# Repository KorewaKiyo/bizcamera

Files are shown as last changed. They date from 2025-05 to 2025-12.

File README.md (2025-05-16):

# BizCamera 
## A credit/business card sized camera

### Why?
I thought it was a cool and silly enough idea to be unique, and I couldn't find anyone else doing it. So I took it on myself to make it happen.

### How?
Initially I wanted to go with something STM32, as the camera module wants 1.8V, and there were some good STM32 MCUs with 1.8v, but it seemed like none of them were fast enough or had enough RAM to grab frames from the sensor. 
So I'm using the RP2350 which with PIO should have enough IO speed to just steal a frame off the data bus.

The chip itself doesn't have enough ram to store an image above 320x240 so I've added some RAM, a flash chip for code, and an SD card slot for storing images.

### What's the output like?
Yet to be seen :>

### What does the board look like?

top
bottom
rendered with [kicad-render](https://github.com/linalinn/kicad-render)

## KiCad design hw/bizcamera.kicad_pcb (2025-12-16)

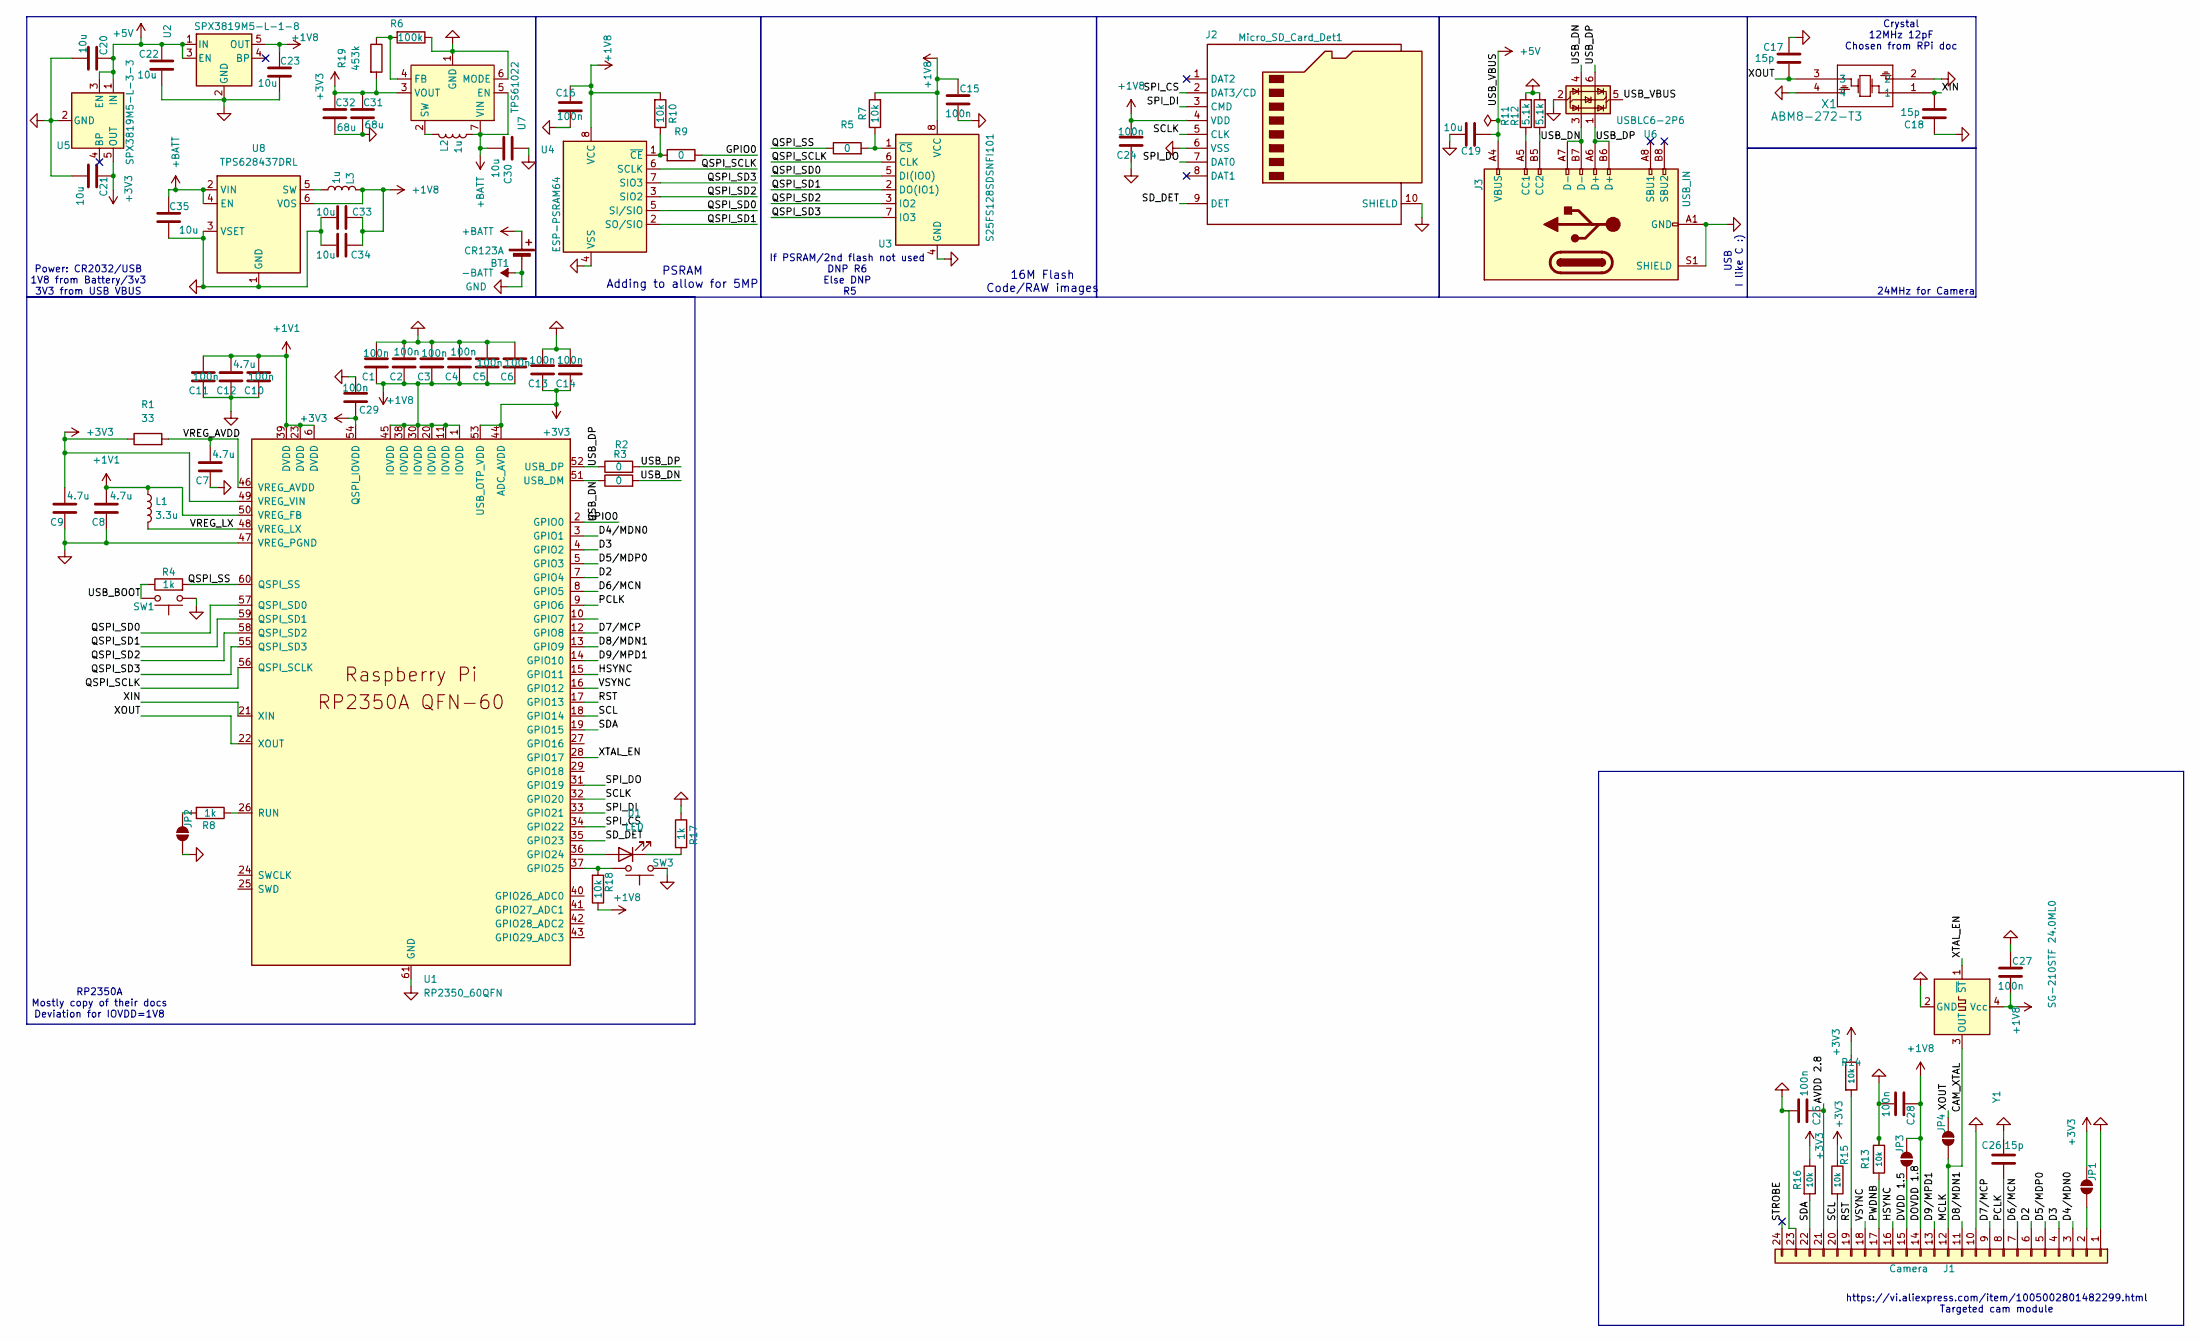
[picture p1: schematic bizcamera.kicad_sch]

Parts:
BT1: CR123A; BatteryHolder_Bulgin_BX0123_1xCR123
C1, C2, C3, C4, C5, C6, C10, C11, C13, C14, C15, C16, C24, C25, C27, C28, C29: 100n; C_0402_1005Metric; LCSC C1525
C7, C8, C9, C12: 4.7u; C_0402_1005Metric; LCSC C76995
C17, C18, C26: 15p; C_0402_1005Metric; LCSC C1548
C19, C20, C21, C22, C23, C30, C33, C34, C35: 10u; C_0603_1608Metric; LCSC C1691
C31, C32: 68u; C_0603_1608Metric; LCSC C7220
D1: LED; LED_1206_3216Metric_ReverseMount_Hole1.8x2.4mm; LCSC C329183
J1: Camera; Hirose_FH12-24S-0.5SH_1x24-1MP_P0.50mm_Horizontal; LCSC C202112
J2: Micro_SD_Card_Det1; microSD_HC_Hirose_DM3D-SF; LCSC C719027
J3: USB_IN; USB_C_Receptacle_HCTL_HC-TYPE-C-16P-01A; LCSC C2894897
JP1: CAM_AF; SolderJumper-2_P1.3mm_Open_RoundedPad1.0x1.5mm
JP2: USB_BOOT; SolderJumper-2_P1.3mm_Open_RoundedPad1.0x1.5mm
JP3: DVDD_1V8; SolderJumper-2_P1.3mm_Open_RoundedPad1.0x1.5mm
JP4: XTAL_JMP; SolderJumper-2_P1.3mm_Open_RoundedPad1.0x1.5mm
L1: 3.3u; L_pol_2016
L2, L3: 1u; TFM201610ALMA; LCSC C404808
R1: 33; R_0402_1005Metric; LCSC C25105
R2, R3, R5, R9: 0; R_0402_1005Metric; LCSC C17168
R4, R8, R17: 1k; R_0402_1005Metric; LCSC C11702
R6: 100k; R_0402_1005Metric_Pad0.72x0.64mm_HandSolder; LCSC C25741
R7, R10, R13, R14, R15, R16, R18: 10k; R_0603_1608Metric; LCSC C15401
R11, R12: 5.1k; R_0603_1608Metric; LCSC C23186
R19: 453k; R_0402_1005Metric_Pad0.72x0.64mm_HandSolder; LCSC C103049
SW1: USB_BOOT; SW_Push_1P1T_NO_CK_KMR2; LCSC C72443
SW3: Shutter; SW_Push_1P1T_NO_6x6mm_H9.5mm; LCSC C22397173
U1: RP2350_60QFN; RP2350-QFN-60-1EP_7x7_P0.4mm_EP3.4x3.4mm_ThermalVias; LCSC C42411118
U2: SPX3819M5-L-1-8; SOT-23-5; LCSC C18212663
U3: S25FS128SDSNFI101; WSON-8-1EP_6x5mm_P1.27mm_EP3.4x4.3mm; LCSC C2954241
U4: ESP-PSRAM64; SOIC-8_3.9x4.9mm_P1.27mm
U5: SPX3819M5-L-3-3; SOT-23-5; LCSC C5370980
U6: USBLC6-2P6; SOT-666; LCSC C2682291
U7: TPS61022; Texas_RWU0007A_VQFN-7_2x2mm_P0.5mm; LCSC C915088
U8: TPS628437DRL; SOT-563; LCSC C25838674
X1: ABM8-272-T3; ABM8-272-T3_ABR; LCSC C20625731
Y1: SG-210STF 24.0ML0; Oscillator_SMD_SeikoEpson_SG210-4Pin_2.5x2.0mm

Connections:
+1V1: C8.1, C10.1, C11.1, C12.1, L1.1, U1.6 (DVDD), U1.23 (DVDD), U1.39 (DVDD), U1.50 (VREG_FB)
+1V8: C1.2, C2.2, C3.2, C4.2, C5.2, C6.2, C15.2, C16.2, C23.1, C24.1, C27.1, C28.2, C33.1, C34.1, J1.14, J2.4 (VDD), JP3.1 (A), L3.2, R7.2, R10.2, R18.1, U1.1 (IOVDD), U1.11 (IOVDD), U1.20 (IOVDD), U1.30 (IOVDD), U1.38 (IOVDD), U1.45 (IOVDD), U2.5 (OUT), U3.8 (VCC), U4.8 (VCC), U8.6 (VOS), Y1.4 (Vcc)
+3V3: C9.1, C13.2, C14.2, C21.1, C29.2, C31.1, C32.1, JP1.1 (A), R1.1, R14.1, R15.1, R16.1, R19.2, U1.44 (ADC_AVDD), U1.49 (VREG_VIN), U1.53 (USB_OTP_VDD), U1.54 (QSPI_IOVDD), U5.5 (OUT), U7.3 (VOUT)
+5V: C19.2, C20.1, C22.1, J3.A4 (VBUS), J3.A9 (VBUS), J3.B4 (VBUS), J3.B9 (VBUS), U2.1 (IN), U2.3 (EN), U5.1 (IN), U5.3 (EN), U6.5 (VBUS)
+BATT: BT1.1 (+), C30.2, C35.1, L2.1, U7.5 (EN), U7.7 (VIN), U8.2 (VIN), U8.4 (EN)
-BATT: BT1.2 (-), C1.1, C2.1, C3.1, C4.1, C5.1, C6.1, C7.2, C8.2, C9.2, C10.2, C11.2, C12.2, C13.1, C14.1, C15.1, C16.1, C17.2, C18.2, C19.1, C20.2, C21.2, C22.2, C23.2, C24.2, C25.1, C26.1, C27.2, C28.1, C29.1, C30.1, C31.2, C32.2, C33.2, C34.2, C35.2, J1.1, J1.10, J1.23, J2.6 (VSS), J2.10 (SHIELD), J3.A1 (GND), J3.A12 (GND), J3.B1 (GND), J3.B12 (GND), J3.S1 (SHIELD), JP2.2 (B), R6.1, R11.2, R12.2, R13.1, R17.1, SW1.1, SW3.1, U1.47 (VREG_PGND), U1.61 (GND), U2.2 (GND), U3.4 (GND), U4.4 (VSS), U5.2 (GND), U6.2 (GND), U7.1 (GND), U7.6 (MODE), U8.1 (GND), U8.3 (VSET), X1.2, X1.4, Y1.2 (GND)
/AVDD 2.8: C25.2, J1.21
/CAM_XTAL: J1.12, JP4.2 (B), Y1.3 (OUT)
/D2: J1.6, U1.7 (GPIO4)
/D3: J1.4, U1.4 (GPIO2)
/D4/MDN0: J1.3, U1.3 (GPIO1)
/D5/MDP0: J1.5, U1.5 (GPIO3)
/D6/MCN: J1.7, U1.8 (GPIO5)
/D7/MCP: J1.9, U1.12 (GPIO8)
/D8/MDN1: J1.11, U1.13 (GPIO9)
/D9/MPD1: J1.13, U1.14 (GPIO10)
/DVDD 1.5: J1.15, JP3.2 (B)
/GPIO0: R9.1, U1.2 (GPIO0)
/HSYNC: J1.16, U1.15 (GPIO11)
/PCLK: C26.2, J1.8, U1.9 (GPIO6)
/PWDNB: J1.17, R13.2
/QSPI_SCLK: U1.56 (QSPI_SCLK), U3.6 (CLK), U4.6 (SCLK)
/QSPI_SD0: U1.57 (QSPI_SD0), U3.5 (DI(IO0)), U4.5 (SI/SIO)
/QSPI_SD1: U1.59 (QSPI_SD1), U3.2 (DO(IO1)), U4.2 (SO/SIO)
/QSPI_SD2: U1.58 (QSPI_SD2), U3.3 (IO2), U4.3 (SIO2)
/QSPI_SD3: U1.55 (QSPI_SD3), U3.7 (IO3), U4.7 (SIO3)
/QSPI_SS: R4.2, R5.1, U1.60 (QSPI_SS)
/RST: J1.19, R14.2, U1.17 (GPIO13)
/SCL: J1.20, R15.2, U1.18 (GPIO14)
/SCLK: J2.5 (CLK), U1.32 (GPIO20)
/SDA: J1.22, R16.2, U1.19 (GPIO15)
/SD_DET: J2.9 (DET), U1.35 (GPIO23)
/SPI_CS: J2.2 (DAT3/CD), U1.34 (GPIO22)
/SPI_DI: J2.3 (CMD), U1.33 (GPIO21)
/SPI_DO: J2.7 (DAT0), U1.31 (GPIO19)
/STROBE: J1.24
/USB_BOOT: R4.1, SW1.2
/USB_DN: J3.A7 (D-), J3.B7 (D-), R3.1, R3.2, U1.51 (USB_DM), U6.3 (I/O2), U6.4 (I/O2)
/USB_DP: J3.A6 (D+), J3.B6 (D+), R2.1, R2.2, U1.52 (USB_DP), U6.1 (I/O1), U6.6 (I/O1)
/VREG_AVDD: C7.1, R1.2, U1.46 (VREG_AVDD)
/VREG_LX: L1.2, U1.48 (VREG_LX)
/VSYNC: J1.18, U1.16 (GPIO12)
/XIN: C18.1, U1.21 (XIN), X1.1
/XOUT: C17.1, JP4.1 (A), U1.22 (XOUT), X1.3
/XTAL_EN: U1.28 (GPIO17), Y1.1 (~ST)
unnamed: D1.2 (A), U1.36 (GPIO24)
unnamed: D1.1 (K), R17.2
unnamed: J1.2, JP1.2 (B)
unnamed: J3.A5 (CC1), R11.1
unnamed: J3.B5 (CC2), R12.1
unnamed: JP2.1 (A), R8.2
unnamed: R18.2, SW3.2, U1.37 (GPIO25)
unnamed: R8.1, U1.26 (RUN)
unnamed: R5.2, R7.1, U3.1 (~CS)
unnamed: R9.2, R10.1, U4.1 (~CE)
unnamed: R6.2, R19.1, U7.4 (FB)
unnamed: L2.2, U7.2 (SW)
unnamed: L3.1, U8.5 (SW)

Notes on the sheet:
16M Flash Code/RAW images
USB I like C :)
Crystal 12MHz 12pF Chosen from RPi doc
If PSRAM/2nd flash not used DNP R6 Else DNP R5
Power: CR2032/USB 1V8 from Battery/3v3 3V3 from USB VBUS
24MHz for Camera
PSRAM Adding to allow for 5MP
RP2350A Mostly copy of their docs Deviation for IOVDD=1V8
https://vi.aliexpress.com/item/1005002801482299.html Targeted cam module

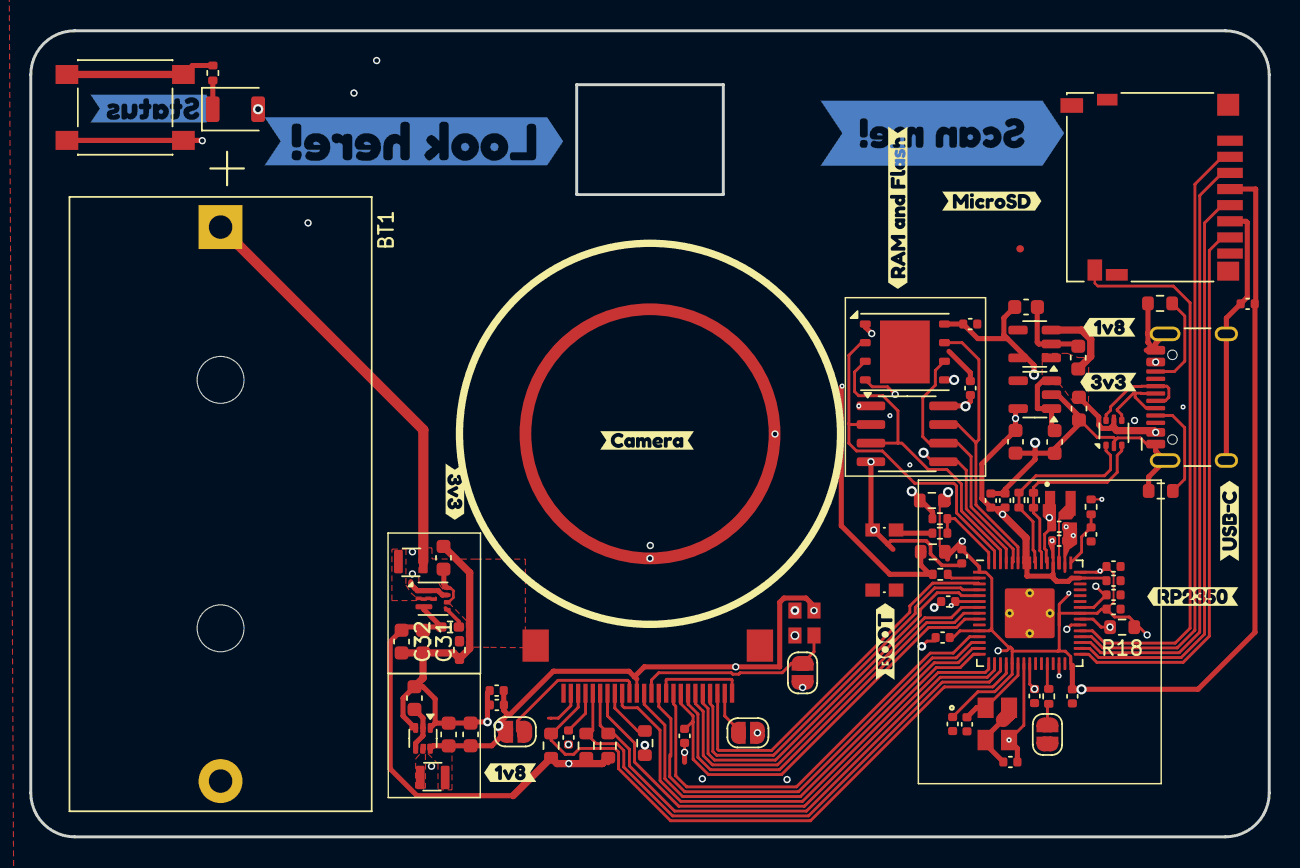
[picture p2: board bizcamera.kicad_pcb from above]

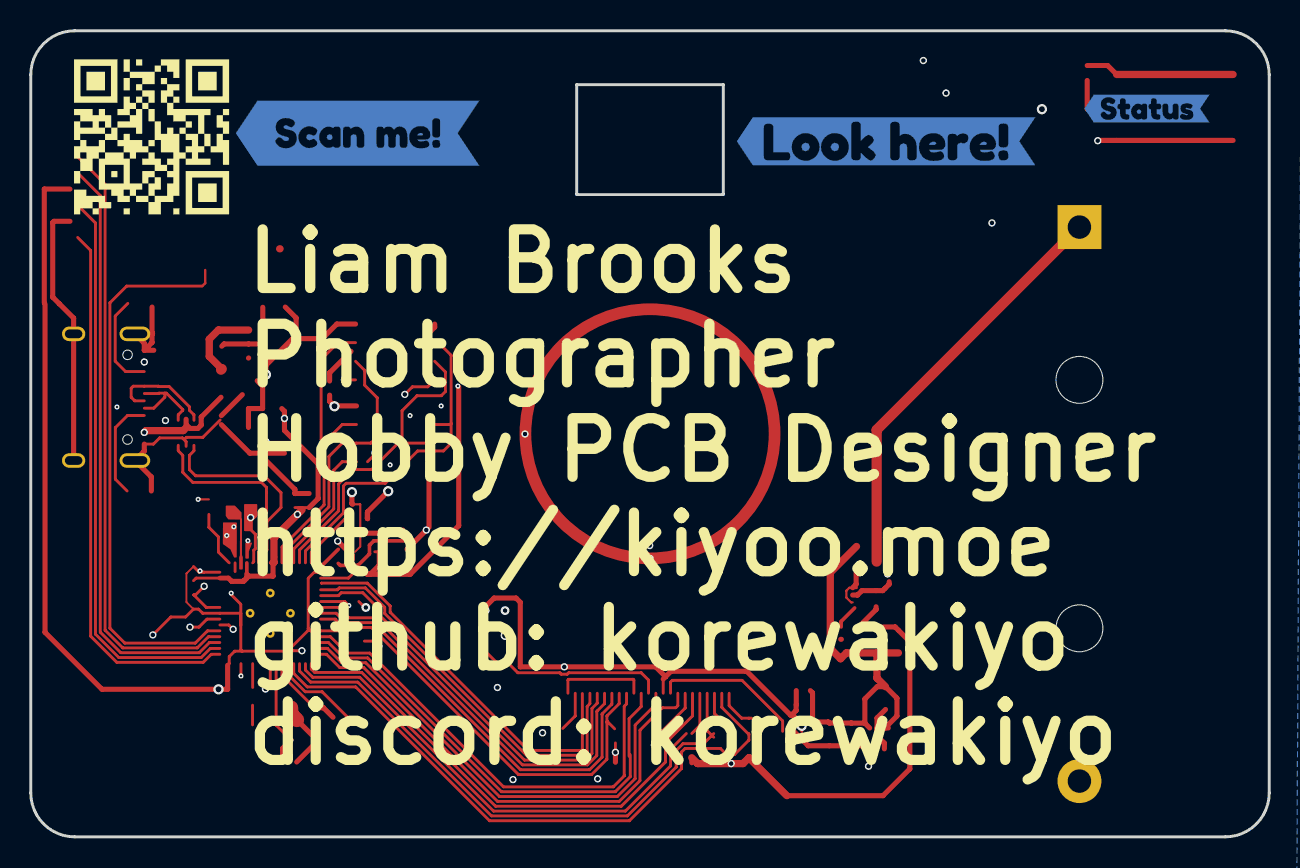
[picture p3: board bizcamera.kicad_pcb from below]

Board: 4 copper layers, 84.5 x 55.0 mm, 92 parts (3 on the bottom side), 57 nets.

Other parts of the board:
kibuzzard-6825B58C: G***; kibuzzard-6825B58C
kibuzzard-68265B48: G***; kibuzzard-68265B48
kibuzzard-68265CCE: G***; kibuzzard-68265CCE
kibuzzard-68265CF0: G***; kibuzzard-68265CF0
kibuzzard-68265EBA: G***; kibuzzard-68265EBA
kibuzzard-68265EEF: G***; kibuzzard-68265EEF
kibuzzard-68265F1C: G***; kibuzzard-68265F1C
kibuzzard-68265F3A: G***; kibuzzard-68265F3A
kibuzzard-68265F49: G***; kibuzzard-68265F49
kibuzzard-68265FBA: G***; kibuzzard-68265FBA
kibuzzard-68265FD3: G***; kibuzzard-68265FD3
kibuzzard-68265FDC: G***; kibuzzard-68265FDC
kibuzzard-682743A4: G***; kibuzzard-682743A4
kibuzzard-68266036: G***; kibuzzard-68266036

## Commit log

2025-04-29 Define project
    Define pcb edge cuts
    [bizcamera.kicad_pcb, bizcamera.kicad_sch]
2025-05-01 Schematic rev1
    Rev1 of the schematic, not finished, but close.
    Switched to rp2350 because PIO is powerful enough to grab frames without DCMI iface
    [bizcamera.kicad_pcb, bizcamera.kicad_sch]
2025-05-02 Finish schematic
    [bizcamera.kicad_pcb, bizcamera.kicad_sch]
2025-05-15 Near final design
    Near final design for prototype model, for both schematic and PCB
    Layout was an absolute nightmare. But I think this is the best I can do with the constraints, and it should look pretty nice too.
    [bizcamera.kicad_pcb, bizcamera.kicad_sch]
2025-05-15 Tidy up
    [bizcamera.kicad_pcb, bizcamera.kicad_sch]
2025-05-15 Styling
    Styling to make it more of a business card :D
    [bizcamera.kicad_pcb]
2025-05-16 BOM and minor rework
    I realised 68u 0603's were impossible lol
    [bizcamera.kicad_pcb, bizcamera.kicad_sch]
2025-12-16 Directory update
    [bizcamera-CuBottom.gbr, bizcamera-CuIn1.gbr, bizcamera-CuIn2.gbr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]
